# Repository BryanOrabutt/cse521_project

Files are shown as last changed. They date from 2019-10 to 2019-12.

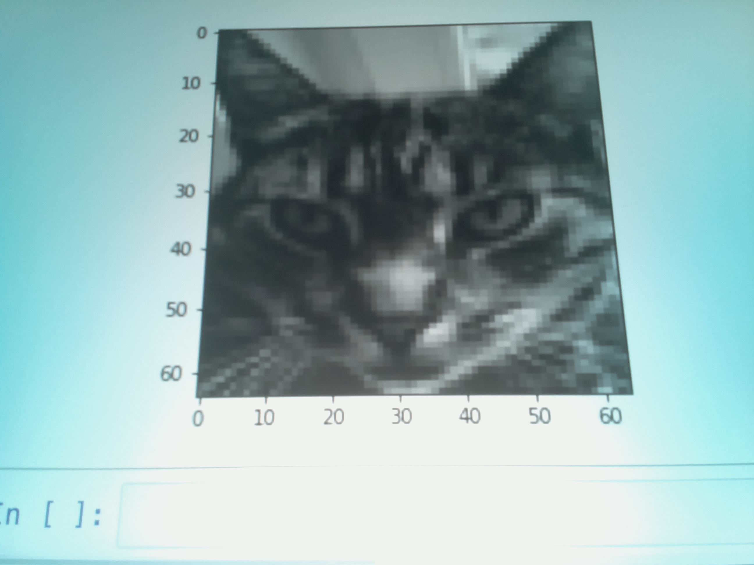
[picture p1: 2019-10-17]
automated_functions/face_recogniction/image.jpg

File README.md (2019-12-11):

# cse521_project

ESP32 code for the project is located in espressif_code/pet-feeder/main. To build the ESP32 code first get the ESP-IDF following these instructions https://docs.espressif.com/projects/esp-idf/en/v3.3/get-started/index.html. Then simply enter the pet-feeder directory and run `make menuconfig` and configure your programmer and WiFi SSID. Then run `make flash -j4` to program the device.

The directory server/src/ contains the code to run the dispense scheduler. This can also be run locally without an AWS EC2 instance. Simply install AWSIoTPythonSDK.MQTTLib with pip and run the petfeeder.py program.

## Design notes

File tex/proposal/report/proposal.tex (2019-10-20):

\documentclass{article}
\usepackage{amsmath}
\title{CSE 521S Project Proposal}
\author{Bryan Orabutt, Gan Xu}

\begin{document}
\maketitle 
\newpage
\section*{Project Description}

Our project idea is to make an automated pet feeder that uses AWS and an Amazon Echo device to allow users to schedule pet feedings for their pets. Using an Alexa device, a user can set times to feed their pet each day, as well as a specified amount of food to feed each pet. Each automated food dispenser will dispense this amount of food at the requested time.\\\\\noindent
We also want to provide useful information back to the user about their pet's eating habits. We want to be able to notify the user when the dispenser is low on food, when the next feeding will be, and when the last feeding was. We also want to use machine learning techniques to offer some insights about their pets' health. We record a pet's typical feeding habits and see how quickly it eats its food, and how often it leaves food left in the bowl. With this information, we can determine a pet's general eating habits and let the pet owner know if their pet is displaying atypical eating patterns that may indicate a health issue.

\section*{Responsibilities}
Bryan will be responsible for the mechanical design and fabrication of parts due to his experience with 3D CAD tools and 3D printing. He will also lead the development of embedded systems code for the ESP32 micro-controller.  Gan will focus on developing machine learning tools for pet health and other ML related functions. Both of us will work together to implement other data analytic tools for the end user. Such as the Amazon Alexa integration, and some mechanism for providing data to the user, such as a mobile app or email notification.

\section*{Equipment}
    \begin{itemize}
        \item IoT capable micro-controller or single board computer.
        \item Power supply or batteries + regulator circuit
        \item Amazon echo
        \item Servo or stepper motor
        \item Weight sensors
        \item Multimeter, oscilloscope, and other test equipment
        \item 3D printer for part fabrication
    \end{itemize}

\section*{Functions}
    \begin{itemize}
        \item Automatic adjustment of dispension amount.
    \end{itemize}

\end{document}

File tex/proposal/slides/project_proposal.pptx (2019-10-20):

## Automatic Pet Feeder

Bryan Orabutt & Gan Xu

## Concept

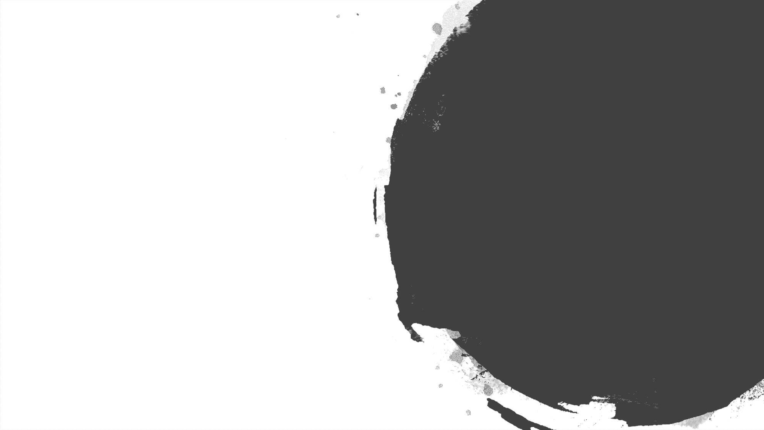
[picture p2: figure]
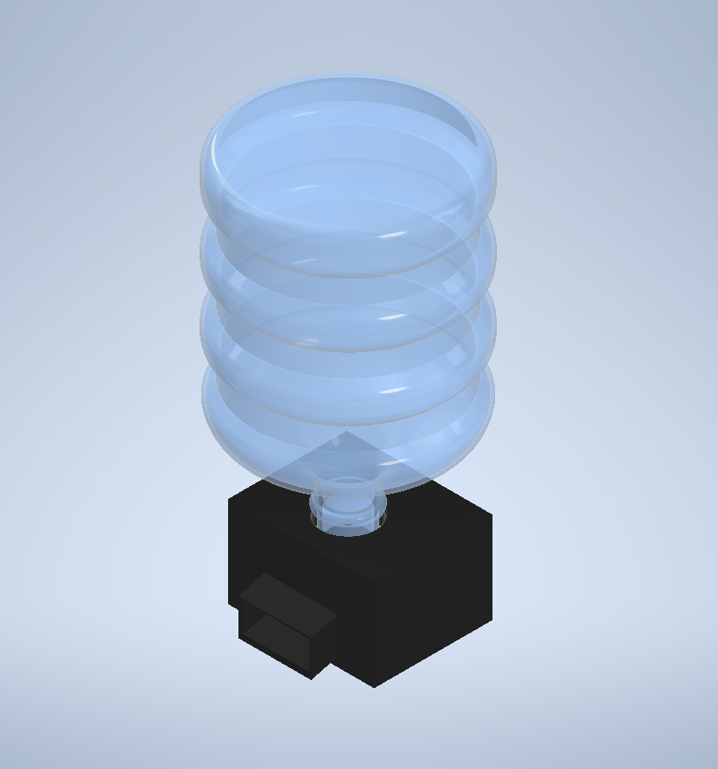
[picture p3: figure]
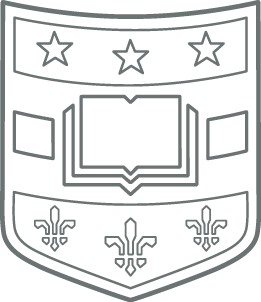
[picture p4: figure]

- Pet feeder will automatically dispense food for pets.
  - Amount controlled by user
  - Time/number of feedings controlled by user
- Amazon Echo/Alexa will allow easy control of device
- Low power battery operated.

## Embedded

- For the device to be battery operated, a low quiescent current draw is needed.
- ESP32 microcontroller is supported by FreeRTOS and offers deep sleep modes for reduced power consumption.
- Motors and sensors need to be powered off when not in use.
- If we cant get AWS working on ESP32 we will use Raspberry Pi and run off wall power supply

## Machine Learning

- Use camera to detect and match pets to their profile if there are multiple pets in the house, adjust the food amount for each pet.
- Based on the food leftover measurement each time, can give user suggestions on food portions adjustments to fit individual pet’s needs.
- Based on the pets body metrics and dieting amount, learning on pets behavior and automatically enable slow feeding to avoid digestive upset or detect atypical pattern and possibly related health issues.

## Hardware & Equipment

- IoT capable microcontroller
  - Espressif ESP32 using FreeRTOS
  - Raspberry Pi (backup plan)
- Amazon Echo
- Servo motors or stepper motors
- Weight sensors
- Camera
- Multimeter, oscilloscope, and other test equipment.
- 3D printer for parts fabrication

## Project Timeline

0%

Oct 13 - Dec 4

53 days

Machine learning

0%

0%

Sep 22 - Dec 4

Oct 13 - Nov 16

74 days

35 days

Alexa integration

Analytics implementation

0%

0%

0%

Sep 8 - Sep 21

Sep 8 - Oct 31

Sep 22 - Oct 5

14 days

Small scale prototyping

14 days

54 days

AWS integration

Mechanical design + fabrication

2019

Sep

Oct

Nov

Dec

2019

Proposal

Sep 12

Today

Nov 21

Demo 1

Oct 17

Demo 2

Final Demo

Dec 5

Bryan

Both

Gan

## Questions?

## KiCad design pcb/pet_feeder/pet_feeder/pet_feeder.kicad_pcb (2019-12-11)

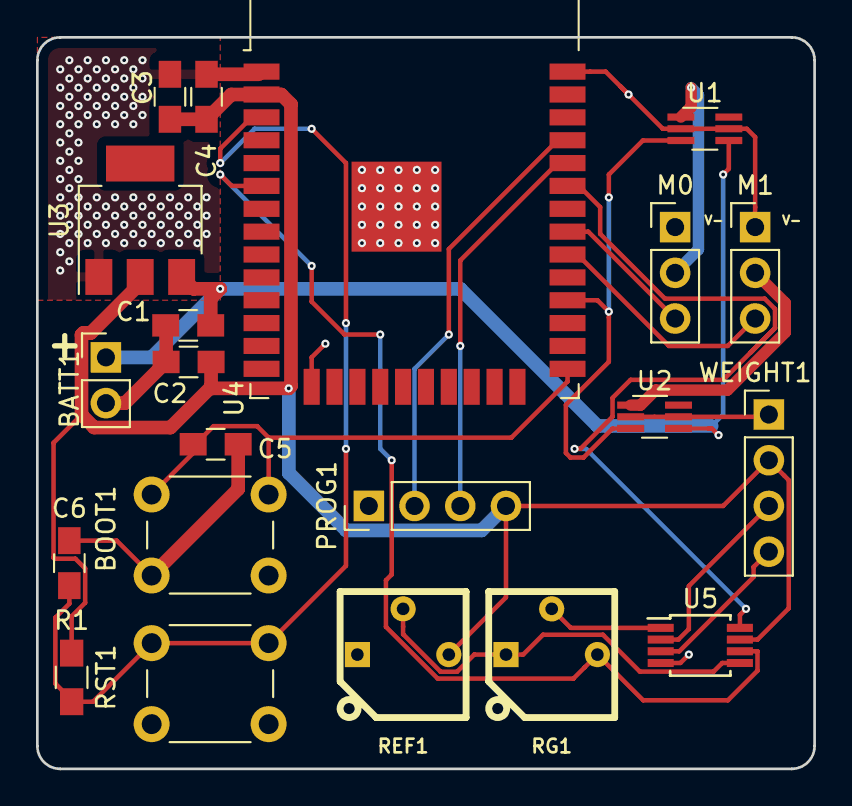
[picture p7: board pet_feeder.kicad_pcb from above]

Board: 2 copper layers, 43.2 x 40.6 mm, 21 parts (0 on the bottom side), 18 nets.

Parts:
BATT1: BATT; Pin_Header_Straight_1x02_Pitch2.54mm
BOOT1: BOOT; SW_PUSH_6mm
C1, C2: 4.7u; C_0805_HandSoldering
C3, C5, C6: 100n; C_0805_HandSoldering
C4: 22u; C_0805_HandSoldering
M0: M0; Pin_Header_Straight_1x03_Pitch2.54mm
M1: M1; Pin_Header_Straight_1x03_Pitch2.54mm
PROG1: PROG; Pin_Header_Straight_1x04_Pitch2.54mm
R1: 10K; R_0805_HandSoldering
REF1: 500K; bourns3362p
RG1: 500K; bourns3362p
RST1: RST; SW_PUSH_6mm
U1, U2: SiP32431; SOT-363_SC-70-6_Handsoldering
U3: AP7361C-33E; SOT-223-3_TabPin2
U4: ESP32-WROOM-32D; ESP32-WROOM-32
U5: INA322; MSOP-8_3x3mm_Pitch0.65mm
WEIGHT1: WEIGHT; Pin_Header_Straight_1x04_Pitch2.54mm

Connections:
+3V3: C2.1, C3.2, C4.2, PROG1.4, R1.2, REF1.3, U3.2, U4.2, U5.7, WEIGHT1.2
+BATT: BATT1.1, C1.1, U1.4, U2.4, U3.3
-BATT: BATT1.2, BOOT1.2, C1.2, C2.2, C3.1, C4.1, C5.2, C6.2, M0.1, M1.1, PROG1.1, REF1.1, RST1.2, U1.2, U1.5, U2.2, U2.5, U3.1, U4.1, U4.15, U4.38, U4.39, U5.4, WEIGHT1.1
/GPIO0: BOOT1.1, C5.1, U4.25
/REF: REF1.2, RG1.1, U5.5
/RG: RG1.2, U5.1
/RST: C6.1, R1.1, RST1.1, U4.3
/RX: PROG1.3, U4.34
/SRV0_PWM: M0.3, U4.31
/SRV1_PWM: M1.3, U4.30
/SRV1_PWR: M1.2, U2.1
/SRV_EN: U1.3, U2.3, U4.28
/SRV_PWR: M0.2, U1.1
/TX: PROG1.2, U4.35
/WS+: U5.3, WEIGHT1.4
/WS-: U5.2, WEIGHT1.3
/WS_ADC: RG1.3, U4.6, U5.6
/~WS_EN: U4.33, U5.8

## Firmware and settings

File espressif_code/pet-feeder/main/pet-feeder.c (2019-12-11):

/*
 * Copyright 2010-2015 Amazon.com, Inc. or its affiliates. All Rights Reserved.
 * Additions Copyright 2016 Espressif Systems (Shanghai) PTE LTD
 *
 * Licensed under the Apache License, Version 2.0 (the "License").
 * You may not use this file except in compliance with the License.
 * A copy of the License is located at
 *
 *  http://aws.amazon.com/apache2.0
 *
 * or in the "license" file accompanying this file. This file is distributed
 * on an "AS IS" BASIS, WITHOUT WARRANTIES OR CONDITIONS OF ANY KIND, either
 * express or implied. See the License for the specific language governing
 * permissions and limitations under the License.
 */
/**
 * @file pet-feeder.c
 * @brief Waits for JSON from AWS and determines whether to dispense food or now. Enters low power when not dispensing or transmitting.
 *
 * This example takes the parameters from the build configuration and establishes a connection to the AWS IoT MQTT Platform.
 * It subscribes to topic "pet-feeder/from_aws" and publishes to topic "pet-feeder/to_aws"
 *
 * Some setup is required. See example README for details.
 *
 */
#include <stdio.h>
#include <stdlib.h>
#include <ctype.h>
#include <unistd.h>
#include <limits.h>
#include <string.h>

#include "freertos/FreeRTOS.h"
#include "freertos/task.h"
#include "freertos/event_groups.h"
#include "freertos/timers.h"

#include "esp_system.h"
#include "esp_wifi.h"
#include "esp_event_loop.h"
#include "esp_log.h"
#include "esp_vfs_fat.h"
#include "driver/sdmmc_host.h"
#include "esp_intr_alloc.h"
#include "esp_sleep.h"
#include "soc/rtc.h"
#include "driver/rtc_io.h"
#include "soc/rtc_cntl_reg.h"
#include "soc/rtc.h"

#include "driver/gpio.h"
#include "driver/ledc.h"
#include "driver/adc.h"
#include "esp_attr.h"

#include "driver/adc.h"
#include "esp_adc_cal.h"

#include "nvs.h"
#include "nvs_flash.h"

#include "aws_iot_config.h"
#include "aws_iot_log.h"
#include "aws_iot_version.h"
#include "aws_iot_mqtt_client_interface.h"


#include "../../json/cJSON/cJSON.h"

#define NOP() asm volatile ("nop")
#define WS_BASELINE 1077
#define WS_GRAMS_PER_COUNT 0.0485608
#define WS_EN 21
#define WS_ADC 34
#define SRV_EN 17
#define AMP_EN 22
#define SRV0 18
#define SRV1 19
#define MOTION 4

#define PWM_CHANNEL0 LEDC_CHANNEL_7
#define PWM_CHANNEL1 LEDC_CHANNEL_6
#define PWM_TIMER0 LEDC_TIMER_3
#define PWM_TIMER1 LEDC_TIMER_3

static const char *TAG = "pet-feeder";
const static int serial_num = 123456;

/* The examples use simple WiFi configuration that you can set via
   'make menuconfig'.

   If you'd rather not, just change the below entries to strings with
   the config you want - ie #define EXAMPLE_WIFI_SSID "mywifissid"
*/
#define EXAMPLE_WIFI_SSID CONFIG_WIFI_SSID
#define EXAMPLE_WIFI_PASS CONFIG_WIFI_PASSWORD


#define SERVO_MIN_PULSEWIDTH 320 //Minimum pulse width in microsecond
#define SERVO_MAX_PULSEWIDTH 2725//Maximum pulse width in microsecond
#define SERVO_MIN_PULSEWIDTH0 320 //Minimum pulse width in microsecond
#define SERVO_MAX_PULSEWIDTH0 2700//Maximum pulse width in microsecond
#define SERVO_MIN_PULSEWIDTH1 320 //Minimum pulse width in microsecond
#define SERVO_MAX_PULSEWIDTH1 2650 //Maximum pulse width in microsecond
#define SERVO_MAX_DEGREE 180 //Maximum angle in degree upto which servo can rotate
#define SERVO_PERIOD 20000.0
#define MAX_TIMER 32767

/* FreeRTOS event group to signal when we are connected & ready to make a request */
static EventGroupHandle_t wifi_event_group;

/* The event group allows multiple bits for each event,
   but we only care about one event - are we connected
   to the AP with an IP? */
const int CONNECTED_BIT = BIT0;

static QueueHandle_t rx_queue;
static QueueHandle_t tx_queue;

static char rx_queue_empty = 0;
static char tx_queue_empty = 0;

/* CA Root certificate, device ("Thing") certificate and device
 * ("Thing") key.

   Example can be configured one of two ways:

   "Embedded Certs" are loaded from files in "certs/" and embedded into the app binary.

   "Filesystem Certs" are loaded from the filesystem (SD card, etc.)

   See example README for more details.
*/
#if defined(CONFIG_EXAMPLE_EMBEDDED_CERTS)

extern const uint8_t aws_root_ca_pem_start[] asm("_binary_aws_root_ca_pem_start");
extern const uint8_t aws_root_ca_pem_end[] asm("_binary_aws_root_ca_pem_end");
extern const uint8_t certificate_pem_crt_start[] asm("_binary_certificate_pem_crt_start");
extern const uint8_t certificate_pem_crt_end[] asm("_binary_certificate_pem_crt_end");
extern const uint8_t private_pem_key_start[] asm("_binary_private_pem_key_start");
extern const uint8_t private_pem_key_end[] asm("_binary_private_pem_key_end");

#elif defined(CONFIG_EXAMPLE_FILESYSTEM_CERTS)

static const char * DEVICE_CERTIFICATE_PATH = CONFIG_EXAMPLE_CERTIFICATE_PATH;
static const char * DEVICE_PRIVATE_KEY_PATH = CONFIG_EXAMPLE_PRIVATE_KEY_PATH;
static const char * ROOT_CA_PATH = CONFIG_EXAMPLE_ROOT_CA_PATH;

#else
#error "Invalid method for loading certs"
#endif

const static float SERVO_MAX_DUTY0 = (float)SERVO_MAX_PULSEWIDTH/SERVO_PERIOD;
const static float SERVO_MAX_DUTY1 = (float)SERVO_MAX_PULSEWIDTH/SERVO_PERIOD;
const static float SERVO_MIN_DUTY0 = (float)SERVO_MIN_PULSEWIDTH/SERVO_PERIOD;
const static float SERVO_MIN_DUTY1 = (float)SERVO_MIN_PULSEWIDTH/SERVO_PERIOD;
static ledc_timer_config_t timer_conf;
static ledc_channel_config_t ledc_conf;

static esp_adc_cal_characteristics_t *adc_chars;
static const adc_channel_t channel = ADC_CHANNEL_6;     //GPIO34 if ADC1, GPIO14 if ADC2
static const adc_atten_t atten = ADC_ATTEN_DB_11;
static const adc_unit_t unit = ADC_UNIT_1;

static char time_dispense = 0;
static char sample_weight = 0;
static int dispense_amount = 0;
static float weight = 0;
static xQueueHandle interrupt_queue = NULL;


static TaskHandle_t weight_task_h, dispense_task_h;

static TimerHandle_t heartbeat_timer;

/**
 * @brief Default MQTT HOST URL is pulled from the aws_iot_config.h
 */
char HostAddress[255] = AWS_IOT_MQTT_HOST;

/**
 * @brief Default MQTT port is pulled from the aws_iot_config.h
 */
uint32_t port = AWS_IOT_MQTT_PORT;


static esp_err_t event_handler(void *ctx, system_event_t *event)
{
    switch(event->event_id) {
    case SYSTEM_EVENT_STA_START:
        esp_wifi_connect();
        break;
    case SYSTEM_EVENT_STA_GOT_IP:
        xEventGroupSetBits(wifi_event_group, CONNECTED_BIT);
        break;
    case SYSTEM_EVENT_STA_DISCONNECTED:
        /* This is a workaround as ESP32 WiFi libs don't currently
           auto-reassociate. */
        esp_wifi_connect();
        xEventGroupClearBits(wifi_event_group, CONNECTED_BIT);
        break;
    default:
        break;
    }
    return ESP_OK;
}

void parse_json(void* params)
{
    cJSON* json_parser = NULL; //root of JSON key:value tree
    cJSON* object = NULL; //JSON object handle
    cJSON* item = NULL; //JSON item handle
    char msg[100]; //xQueue message handle
    char valid = 0; //Valid flag for logging
    
    
    /* Parse JSON messages from AWS.
     * Create cJSON tree.
     * Iterate over 'request' keys.
     * Iterate over 'update' keys.
     * repeat indefinitely
     */
    while(1)
    {
        //check if Queue has msg, wait one tick
        if(xQueueReceive(rx_queue, msg, (TickType_t) 1))
        {      
            ESP_LOGI(TAG, "JSON received: \n%.*s", strlen(msg), msg);
            json_parser = cJSON_Parse(msg); //create cJSON tree from message
            if(json_parser == NULL)
            {
                const char *error_ptr = cJSON_GetErrorPtr();
                if (error_ptr != NULL)
                {
                    ESP_LOGE(TAG, "Could not build JSON tree");
                    cJSON_Delete(json_parser);
                    continue;
                }
            }
            
            //Point object handle at request objects
            object = cJSON_GetObjectItemCaseSensitive(json_parser, "request");
            if (object)
            {
                ESP_LOGI(TAG, "Received request from AWS");
                cJSON_ArrayForEach(item, object)
                {
                    //set time_dispense flag for dispenser() vTask
                    if(strncmp(item->valuestring, "dispense", 10) == 0)
                    {
                        ESP_LOGI(TAG, "Dispense requested");
                        time_dispense = 1;
                        valid = 1;
                        vTaskResume(dispense_task_h);
                    }
                    //set sample_weight flag for weight_sensor() vTask
                    else if(strncmp(item->valuestring, "weight", 10) == 0)
                    {
                        ESP_LOGI(TAG, "Weight requested");
                        sample_weight = 1;
                        valid = 1;
                        vTaskResume(weight_task_h);
                    }
                    //set invalid JSON
                    else
                    {
                        valid = 0;
                    }
                }
            }
            else
            {
                valid = 0;
            }
            
            //point object handle at update objects
            object = cJSON_GetObjectItemCaseSensitive(json_parser, "update");            
            if (cJSON_IsNumber(object) && (object->valueint >= 0))
            {
                ESP_LOGI(TAG, "Received weight update request from AWS");
           
                valid = 1;
                dispense_amount = (int)object->valueint;
            }
            else if(object)
            {
                valid = 0;
            }
            
            object = cJSON_GetObjectItemCaseSensitive(json_parser, "status");
            if(cJSON_IsNumber(object) && (object->valueint == 1))
            {
                ESP_LOGI(TAG, "Received heartbeat from AWS");
                valid = 1;
            }
            else if(object)
            {
                valid = 0;
            }
                       
            //free JSON tree
            cJSON_Delete(json_parser);
            
            //reset valid
            if(valid)
            {
                valid = 0;
                ESP_LOGI(TAG, "State: time_dispense = %d\t sample_weight = %d\t dispense_amount = %d", time_dispense, sample_weight, dispense_amount);
                xTimerReset(heartbeat_timer, 10);
            }
            //invalid JSON, log error
            else
            {
                ESP_LOGE(TAG, "Invalid request from AWS.\n");
            }
        }
        else
        {
            rx_queue_empty = 1;
        }
        vTaskDelay(10);
    }
}

static void IRAM_ATTR motion_isr(void* arg)
{
    uint32_t gpio_num = (uint32_t) arg;
    xQueueSendFromISR(interrupt_queue, &gpio_num, NULL);
}

void motion_task(void* params)
{
    uint32_t io_num;
    char id = 'm';
    while(1)
    {
        if(xQueueReceive(interrupt_queue, &io_num, 10))
        {
            ESP_LOGI(TAG, "Motion tripped");
            tx_queue_empty = 0;
            xQueueSend(tx_queue, (void*)&id, (TickType_t)0);
        }
        vTaskDelay(100);
    }
}

void heartbeat_timeout(TimerHandle_t xTimer)
{
    ESP_LOGW(TAG, "The dispenser has not heard from AWS in over 15 minutes. Dispensing food now...");
    time_dispense = 1;
    xTimerReset(heartbeat_timer, 10);
}

//copied from ESP32 Arduino library
unsigned long IRAM_ATTR micros()
{
    return (unsigned long) (esp_timer_get_time());
}

//copied from ESP32 Arduino library
void IRAM_ATTR delayMicroseconds(uint32_t us)
{
    uint32_t m = micros();
    if(us){
        uint32_t e = (m + us);
        if(m > e){ //overflow
            while(micros() > e){
                NOP();
            }
        }
        while(micros() < e){
            NOP();
        }
    }
}

uint32_t calculate_duty(uint32_t angle, char motor)
{
    float duty;
    if(motor == 0)
    {
        duty = SERVO_MIN_DUTY0 + (((SERVO_MAX_PULSEWIDTH0 - SERVO_MIN_PULSEWIDTH0) * (angle)) / (SERVO_MAX_DEGREE))/SERVO_PERIOD;
    
        duty = (float)MAX_TIMER*duty;
    }
    else
    {
        duty = SERVO_MIN_DUTY1 + (((SERVO_MAX_PULSEWIDTH1 - SERVO_MIN_PULSEWIDTH1) * (angle)) / (SERVO_MAX_DEGREE))/SERVO_PERIOD;
    
        duty = (float)MAX_TIMER*duty;
    }
    uint32_t duty_int = (uint32_t)duty;
    
    return duty_int;
}

void dispense_task(void* params)
{
    uint32_t timer_duty0;
    uint32_t timer_duty1;
    char id = 'd';
    volatile int32_t count;
    while(1) 
    {
        if(time_dispense)
        {
            ESP_LOGI(TAG, "Dispensing %d grams of food", dispense_amount);
            gpio_set_level(SRV_EN, 1);
            
            for (count = 0; count < SERVO_MAX_DEGREE-39; count+=5) 
            {
                timer_duty0 = calculate_duty(count,0);
                timer_duty1 = calculate_duty(SERVO_MAX_DEGREE-39-count,1);
                ledc_set_duty_and_update(LEDC_HIGH_SPEED_MODE, PWM_CHANNEL0, timer_duty0, 0);
                ledc_set_duty_and_update(LEDC_HIGH_SPEED_MODE, PWM_CHANNEL1, timer_duty1, 0);
                if(weight < ((float)dispense_amount))
                {
                    vTaskDelay(2/portTICK_RATE_MS);    
                }
                else
                {
                    break;
                }
            }
            
            while(weight < ((float)dispense_amount))
            {
               delayMicroseconds(100);   
            }     
            
            for (count = SERVO_MAX_DEGREE-39; count >= 0; count-=15) 
            {
                timer_duty0 = calculate_duty(count,0);
                timer_duty1 = calculate_duty(SERVO_MAX_DEGREE-39-count,1);
                ledc_set_duty_and_update(LEDC_HIGH_SPEED_MODE, PWM_CHANNEL0, timer_duty0, 0);
                vTaskDelay(2/portTICK_RATE_MS);     
            }
           
            time_dispense = 0;
            tx_queue_empty = 0;
            xQueueSend(tx_queue, (void*)&id, (TickType_t)0);
            gpio_set_level(SRV_EN, 0);
        }
        
        vTaskSuspend(0);
        //vTaskDelay(1000/portTICK_RATE_MS);
            
    }
}

void weight_task(void* params)
{
    char id = 'w';
    char cycles;
    char iter;
    int reading;
    
    while(1)
    {
        if(sample_weight)
        {
            gpio_set_level(WS_EN, 0);
            reading = 0;
            sample_weight = 0;
            
            delayMicroseconds(20);
            
            for(iter = 0; iter < 64; iter++)
            {
                reading += adc1_get_raw((adc1_channel_t)channel);
            }
            
            reading /= 64;
            weight = ((float)(reading-WS_BASELINE))*WS_GRAMS_PER_COUNT;
            gpio_set_level(WS_EN, 1);
            sample_weight = 0;
            tx_queue_empty = 0;
            xQueueSend(tx_queue, (void*)&id, (TickType_t)0);        
        }
        
        vTaskSuspend(0);
        //vTaskDelay(1000/portTICK_RATE_MS);
    }
}

void iot_subscribe_callback_handler(AWS_IoT_Client *pClient, char *topicName, uint16_t topicNameLen,
                                    IoT_Publish_Message_Params *params, void *pData) {
    ESP_LOGI(TAG, "Subscribe callback");
    ESP_LOGI(TAG, "%.*s\t%.*s", topicNameLen, topicName, (int) params->payloadLen, (char *)params->payload);
    
    char msg[200];
    strncpy(msg, params->payload, params->payloadLen);
    strcat(msg, "\0");
    rx_queue_empty = 0;
    xQueueSend(rx_queue, (void*)msg, (TickType_t) 0);
}

void disconnectCallbackHandler(AWS_IoT_Client *pClient, void *data) {
    ESP_LOGW(TAG, "MQTT Disconnect");
    IoT_Error_t rc = FAILURE;

    if(NULL == pClient) {
        return;
    }

    if(aws_iot_is_autoreconnect_enabled(pClient)) {
        ESP_LOGI(TAG, "Auto Reconnect is enabled, Reconnecting attempt will start now");
    } else {
        ESP_LOGW(TAG, "Auto Reconnect not enabled. Starting manual reconnect...");
        rc = aws_iot_mqtt_attempt_reconnect(pClient);
        if(NETWORK_RECONNECTED == rc) {
            ESP_LOGW(TAG, "Manual Reconnect Successful");
        } else {
            ESP_LOGW(TAG, "Manual Reconnect Failed - %d", rc);
        }
    }
}

void aws_iot_task(void *param) {
    char cPayload[100];

    //int32_t i = 0;
    cJSON* msg_for_aws = NULL;
    cJSON* msg_for_motion = NULL;
    cJSON* data = NULL;
    char id;
    char* str;
    char motion_flag = 0;
        

    IoT_Error_t rc = FAILURE;

    AWS_IoT_Client client;
    IoT_Client_Init_Params mqttInitParams = iotClientInitParamsDefault;
    IoT_Client_Connect_Params connectParams = iotClientConnectParamsDefault;

    IoT_Publish_Message_Params paramsQOS0;
   // IoT_Publish_Message_Params paramsQOS1;

    ESP_LOGI(TAG, "AWS IoT SDK Version %d.%d.%d-%s", VERSION_MAJOR, VERSION_MINOR, VERSION_PATCH, VERSION_TAG);

    mqttInitParams.enableAutoReconnect = false; // We enable this later below
    mqttInitParams.pHostURL = HostAddress;
    mqttInitParams.port = port;

#if defined(CONFIG_EXAMPLE_EMBEDDED_CERTS)
    mqttInitParams.pRootCALocation = (const char *)aws_root_ca_pem_start;
    mqttInitParams.pDeviceCertLocation = (const char *)certificate_pem_crt_start;
    mqttInitParams.pDevicePrivateKeyLocation = (const char *)private_pem_key_start;

#elif defined(CONFIG_EXAMPLE_FILESYSTEM_CERTS)
    mqttInitParams.pRootCALocation = ROOT_CA_PATH;
    mqttInitParams.pDeviceCertLocation = DEVICE_CERTIFICATE_PATH;
    mqttInitParams.pDevicePrivateKeyLocation = DEVICE_PRIVATE_KEY_PATH;
#endif

    mqttInitParams.mqttCommandTimeout_ms = 20000;
    mqttInitParams.tlsHandshakeTimeout_ms = 5000;
    mqttInitParams.isSSLHostnameVerify = true;
    mqttInitParams.disconnectHandler = disconnectCallbackHandler;
    mqttInitParams.disconnectHandlerData = NULL;
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
void app_main()
{
    // Initialize NVS.
    esp_err_t err = nvs_flash_init();
    if (err == ESP_ERR_NVS_NO_FREE_PAGES || err == ESP_ERR_NVS_NEW_VERSION_FOUND) {
        ESP_ERROR_CHECK(nvs_flash_erase());
        err = nvs_flash_init();
    }
    ESP_ERROR_CHECK( err );
    
    rx_queue = xQueueCreate(5, 200*sizeof(char));
    tx_queue = xQueueCreate(10, sizeof(char));
    
    if(rx_queue == 0)
    {
        ESP_LOGE(TAG, "Failed to create message queue");
    }

    //configure high speed PWM timer
    timer_conf.duty_resolution = LEDC_TIMER_15_BIT;
    timer_conf.freq_hz = 50;
    timer_conf.speed_mode = LEDC_HIGH_SPEED_MODE;
    timer_conf.timer_num = PWM_TIMER0;
    ledc_timer_config(&timer_conf);
    
    //configure high speed PWM channel
    ledc_conf.channel = PWM_CHANNEL0;
    ledc_conf.duty = 0;
    ledc_conf.gpio_num = SRV0;
    ledc_conf.intr_type = LEDC_INTR_DISABLE;
    ledc_conf.speed_mode = LEDC_HIGH_SPEED_MODE;
    ledc_conf.timer_sel = PWM_TIMER0;
    ledc_channel_config(&ledc_conf);
    
    timer_conf.duty_resolution = LEDC_TIMER_15_BIT;
    timer_conf.freq_hz = 50;
    timer_conf.speed_mode = LEDC_HIGH_SPEED_MODE;
    timer_conf.timer_num = PWM_TIMER1;
    ledc_timer_config(&timer_conf);
    
    
    ledc_conf.channel = PWM_CHANNEL1;
    ledc_conf.duty = 0;
    ledc_conf.gpio_num = SRV1;
    ledc_conf.intr_type = LEDC_INTR_DISABLE;
    ledc_conf.speed_mode = LEDC_HIGH_SPEED_MODE;
    ledc_conf.timer_sel = PWM_TIMER1;
    ledc_channel_config(&ledc_conf);
    
    ledc_fade_func_install(ESP_INTR_FLAG_LEVEL1);
    
    gpio_config_t io_conf;
    
    //disable interrupt
    io_conf.intr_type = GPIO_PIN_INTR_DISABLE;
    //set as output mode
    io_conf.mode = GPIO_MODE_OUTPUT;
    //bit mask of the pins that you want to set,
    io_conf.pin_bit_mask = (1ULL<<WS_EN | 1ULL<<SRV_EN);
    //disable pull-down mode
    io_conf.pull_down_en = 0;
    //disable pull-up mode
    io_conf.pull_up_en = 0;
    //configure GPIO with the given settings
    gpio_config(&io_conf);
    
    //interrupt of rising edge
    io_conf.intr_type = GPIO_PIN_INTR_POSEDGE;
    //bit mask of the pins, use GPIO4/5 here
    io_conf.pin_bit_mask = (1ULL<<MOTION);
    //set as input mode    
    io_conf.mode = GPIO_MODE_INPUT;
    //enable pull-up mode
    io_conf.pull_down_en = 1;
    gpio_config(&io_conf);
    
    gpio_set_level(WS_EN, 1);
    gpio_set_level(SRV_EN, 0);

    
    //create a queue to handle gpio event from isr
    interrupt_queue = xQueueCreate(10, sizeof(uint32_t));
    
    //Configure ADC
    if (unit == ADC_UNIT_1) 
    {
        adc1_config_width(ADC_WIDTH_BIT_12);
        adc1_config_channel_atten(channel, atten);
    } 
    else 
    {
        adc2_config_channel_atten((adc2_channel_t)channel, atten);
    }
    
	heartbeat_timer = xTimerCreate("heartbeat_timer", pdMS_TO_TICKS(900000), pdTRUE, (void*) 0, heartbeat_timeout);

    initialise_wifi();
    xTaskCreatePinnedToCore(&aws_iot_task, "aws_iot_task", 9516, NULL, 5, NULL, 1);
    
    ESP_LOGI(TAG, "Creating JSON parsing task");
    xTaskCreate(&parse_json, "parse_json_task", 5000, NULL, 4, NULL);
    xTaskCreate(&motion_task, "motion_task", 2500, NULL, 3, NULL);
    
    xTaskCreate(&dispense_task, "dispenser_task", 5000, NULL, 2, &dispense_task_h);
    xTaskCreate(&weight_task, "weight_task", 5000, NULL, 2, &weight_task_h);
    
    //install gpio isr service
    gpio_install_isr_service(0);
    
    //hook isr handler for specific gpio pin
    gpio_isr_handler_add(MOTION, motion_isr, (void*) MOTION);
    
    esp_sleep_enable_timer_wakeup(5000000); //wakeup every 5 seconds;
    rtc_gpio_pullup_en(SRV_EN);
    rtc_gpio_pulldown_en(MOTION);
    esp_sleep_enable_ext1_wakeup(GPIO_NUM_4, ESP_EXT1_WAKEUP_ANY_HIGH);
    rtc_gpio_isolate(GPIO_NUM_12);
    
}

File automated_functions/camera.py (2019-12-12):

"""
The script running on raspberry pi to take a picture and
1) do facial recognition locally or
2) send to cloud for processing

"""

from picamera import PiCamera
import datetime
from time import sleep
from AWSIoTPythonSDK.MQTTLib import AWSIoTMQTTClient

camera = PiCamera()
camera.resolution = (2592, 1944)

root_cert = '../aws-auth/AmazonRootCA1.pem'
private_key = '../aws-auth/951ad5141e-private.pem.key'
cert = '../aws-auth/951ad5141e-certificate.pem.crt'

def sub_cb(self):
	camera.start_preview()
	sleep(1)
	camera.capture('/home/pi/Desktop/gx_folder/image.jpg')
	camera.stop_preview()
	aws_client.publish(self.pub_topic, "message_received", 0)


ip_addr='a2ot5vs3yt7xtc-ats.iot.us-west-2.amazonaws.com'
port=8883
aws_client = AWSIoTMQTTClient("motion")
aws_client.configureEndpoint(ip_addr, port)
aws_client.configureCredentials(root_cert, private_key, cert)

aws_client.configureAutoReconnectBackoffTime(1, 32, 20)
aws_client.configureOfflinePublishQueueing(-1)  # Infinite offline Publish queueing
aws_client.configureDrainingFrequency(2)  # Draining: 2 Hz
aws_client.configureConnectDisconnectTimeout(10)  # 10 sec
aws_client.configureMQTTOperationTimeout(5)  # 5 sec
aws_client.connect()
sub_topic = "pet-feeder/motion"
pub_topic = "pet-feeder/test"
aws_client.subscribe(sub_topic, 1, sub_cb)

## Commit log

2019-09-08 Wifi powersave working.
2019-09-12 Servo example working. Deep and light sleeps work. Need to do AWS
2019-09-18 add face_detecttion
    prototype
2019-09-19 Modified example allowing AWS servo control working
2019-09-30 Bug in using xQueues to receive data... ESP and AWS can hear themselves talk
    [aws-servo.c, deep_sleep_example_main.c, example_test.py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]
2019-10-16 Load cell sensor not working. Need to fix timing issues
    [adc1_example_main.c, gpio_example_main.c, pet-feeder.c]
2019-10-17 update
    some update
    [weight.csv]
2019-10-19 Changed mcpwm for ledc for increased timer resolution
2019-10-20 Fixed servo jitter issue
    [led-servo.c, pet-feeder.c]
2019-10-29 Working on weight sensor code
2019-10-29 Adding pcb files
    [pet_feeder-B.Cu.gbr, pet_feeder-B.Mask.gbr, pet_feeder-B.Paste.gbr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]
2019-10-29 Force commiting kicad .lib files
2019-10-30 Board revision 2 done
    [pet_feeder.kicad_pcb]
2019-10-30 Fixed gerber archive
    [pet_feeder-B_Cu.gbr, pet_feeder-B_Mask.gbr, pet_feeder-B_Paste.gbr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]
2019-10-31 Weight sensor code in place
2019-11-05 Motion sensor working
2019-11-21 Fix server crashing from race condition. Fix dispense mode torque
    [pet-feeder.c]
